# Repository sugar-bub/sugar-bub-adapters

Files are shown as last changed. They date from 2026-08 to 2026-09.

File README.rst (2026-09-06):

Sugar Bub Adapters
==================

.. contents::

Cartridge Hardware
------------------

Cartridge hardware is built around a 45-pin FPC cable. One end connects to a cartridge-type PCB:

* `Base Adapter`_
* `GG Adapter`_

The other end connects to a slot-type PCB:

* `RetroSix GameSlot`_
* `SMS Adapter`_
* `SG-1000 Adapter`_

.. _RetroSix GameSlot: https://retrosix.co.uk/Game-Gear-GameSlot-Kit-p515558760

Base Adapter
~~~~~~~~~~~~

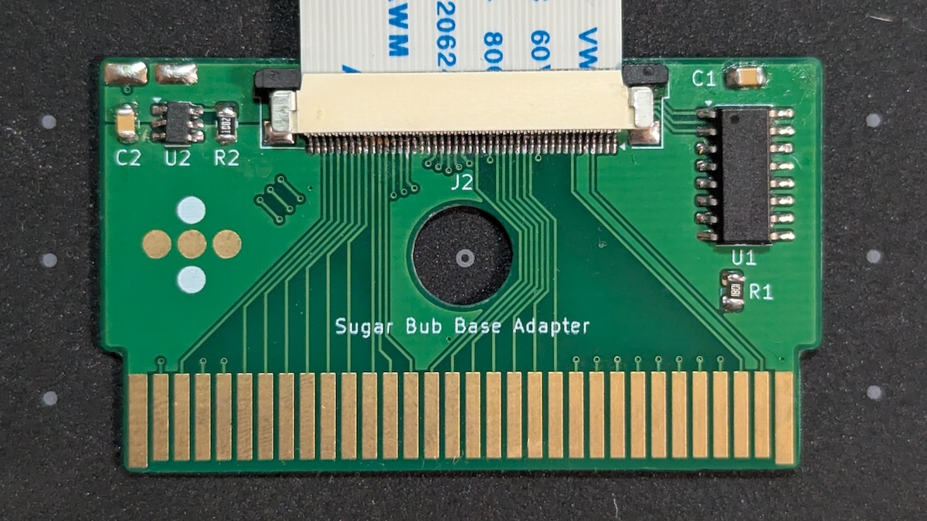
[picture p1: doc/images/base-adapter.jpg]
Base adapter with all components populated for Analogue Pocket compatibility.


The base adapter can be inserted into a Game Boy cartridge slot. It adapts the Game Boy cartridge interface to a FPC connector with the same pinout mapping as the `Analogue AP-A01`_ Sega Game Gear adapter. This FPC connector can be connected directly to a `RetroSix GameSlot`_ or the Sugar Bub `SMS Adapter`_.

By harvesting the MCU from an AP-A01, the adapter can be made compatible with the `Analogue Pocket`_. However, without harvesting the MCU_ or reverse-engineering its communication protocol, the Pocket will not recognize the adapter.

.. _Analogue AP-A01: https://github.com/sfiera/pocket-adapters/blob/main/gg.md
.. _Analogue Pocket: https://www.analogue.co/pocket
.. _MCU: https://github.com/sfiera/pocket-adapters/blob/main/mcu.md

PCB requirements:

* ENIG or hard gold finish (not HASL)
* 0.8mm thickness

Components:

* FPC cable (45p, 0.5mm pitch)
* J2: Amphenol F32Q-1A7H1-11045 FPC connector (45p, 0.5mm pitch)
* U1: SOIC-16 HC139 demux
* C1: 0.1uF 0805 SMD capacitor
* (optional) U2: MCU from Analogue AP-A01
* (optional) C2: 0.1uF 0805 SMD capacitor
* (optional) R1: 1.2k 0805 SMD resistor
* (optional) R2: 10k 0805 SMD resistor
* (optional) D1: 0402 IR LED

SMS Adapter
~~~~~~~~~~~

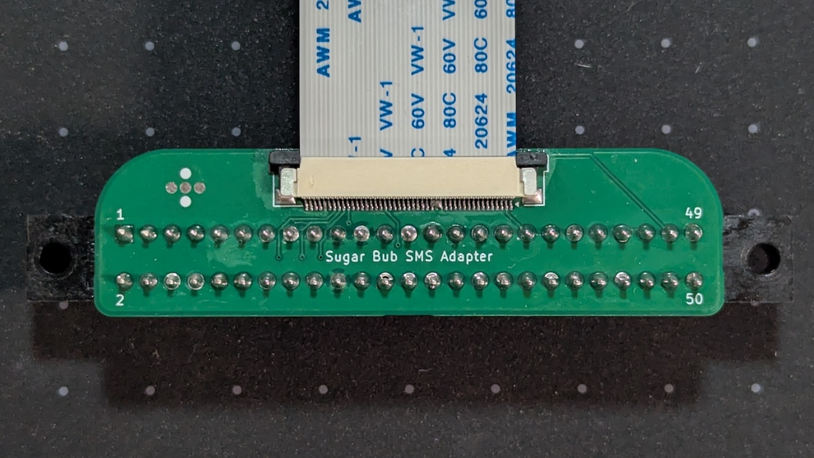
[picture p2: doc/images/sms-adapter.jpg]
SMS adapter with components soldered.


In combination with the `base adapter`_, the SMS adapter serves as a `Master Gear Converter`_ without the need of an intermediate Game Gear slot.

.. _Master Gear Converter: https://segaretro.org/Master_Gear_Converter

PCB requirements:

* Any finish
* Any thickness

Components:

* Amphenol F32Q-1A7H1-11045 FPC connector (45p, 0.5mm pitch)
* EDAC 395-050-521-802 edge connector (50-pin, 2.54 mm pitch)

SG-1000 Adapter
~~~~~~~~~~~~~~~

  **Warning**

  Still needs work. Through-hole diameter is too small.

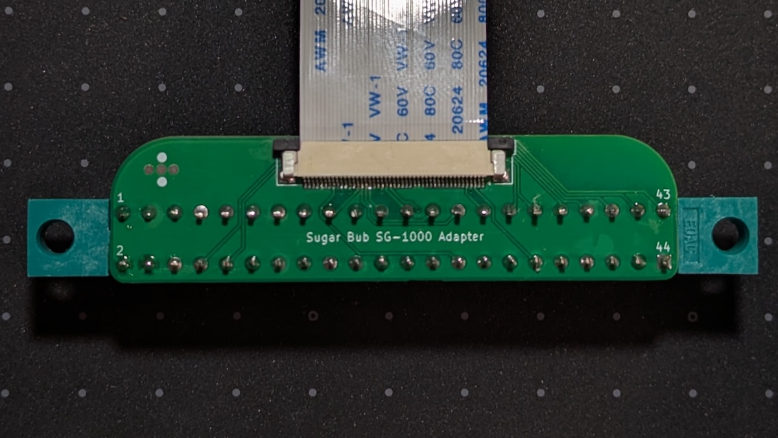
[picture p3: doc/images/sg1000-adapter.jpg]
SG-1000 adapter with components soldered.


In combination with the `base adapter`_, the SG-1000 adapter serves as a `Master Gear Converter`_ for Japanese cartridges without the need of an intermediate Game Gear slot or region converter.

PCB requirements:

* Any finish
* Any thickness

Components:

* Amphenol F32Q-1A7H1-11045 FPC connector (45p, 0.5mm pitch)
* EDAC 346-044-560-204 edge connector (44-pin, 3.175mm pitch)

GG Adapter
~~~~~~~~~~

The GG adapter can be inserted into a Game Gear cartridge slot. It adapts the Game Gear cartridge interface to a FPC connector with the same pinout. This FPC connector can be connected to the Sugar Bub `SMS Adapter`_ to serve as a `Master Gear Converter`_.

Note that the +34V pin is left unconnected. This pin is used only by the TV Tuner.

PCB requirements:

* ENIG or hard gold finish (not HASL)
* 1.0mm thickness

Components:

* FPC cable (45p, 0.5mm pitch)
* J2: Amphenol F32Q-1A7H1-11045 FPC connector (45p, 0.5mm pitch)

Link Hardware
-------------

Link hardware is built around a classic `Macintosh printer cable`_. Like the `Gear-to-Gear cable`_, this is an 8-core cable with 3 crossover pairs. Unlike the Gear-to-Gear cable, it uses a standard 8-pin Mini-DIN connector.

If purchasing a cable, you need one with the following wiring (`example cable`_):

* 1 → 2, 2 → 1
* 3 → 5, 4 → 4, 5 → 3
* 6 → 8, 7 → 7, 8 → 6

.. _Macintosh printer cable: https://whitefiles.org/tec/pgs/h10b.htm
.. _Gear-to-Gear cable: https://segaretro.org/Gear-to-Gear_Cable
.. _example cable: https://www.ebay.com/itm/371981646916

GG Link Adapter
~~~~~~~~~~~~~~~

  **Warning**

  Untested!

The GG link adapter plugs into a `Master Link Cable`_, which in turn plugs into a Game Gear’s EXT port in place of a Gear-to-Gear cable.

.. _Master Link Cable: https://segaretro.org/Master_Link_Cable

Pmod Link Adapter
~~~~~~~~~~~~~~~~~

  **Warning**

  Untested!

The Pmod link adapter plugs into the Pmod connector on top of a `Game Bub`_. It also requires connection to the link port by a Game Boy (not GBA) link cable.

.. _Game Bub: https://gamebub.net/

Q&A
---

Q: What hardware is compatible with the `Base Adapter`_?
  A: Compatible hardware currently includes:

  * `Analogue Pocket`_, which can play games if U2 is harvested from an `Analogue AP-A01`_
  * `GBxCart RW`_, which can use cartload_ to back up cartridges

  Support is planned for `Game Bub`_.

.. _GBxCart RW: https://www.gbxcart.com/
.. _cartload: https://cartload.org/

Q: What’s the use of supporting the Pocket if you need to cannibalize an existing adapter?
  A: Not much, truthfully. But there are a couple of minor reasons you might prefer it:

  * You can use same adapter on all systems, which is slightly more convenient.
  * You can access the `output of U2`_ from a solder pad, which simplifies reverse-engineering.
  * You can connect an `SMS Adapter`_ or `SG-1000 Adapter`_, which means fewer adapters to play SMS/SG-1000.
  * You can customize the adapter shell, which lets the Game Gear (or other) cartridge sit lower.

.. _output of U2: https://github.com/sfiera/pocket-adapters/blob/main/mcu.md

Q: Will there be a link adapter for the Pocket?
  A: No, Gear-to-Gear cables have 7 data pins, and there’s no good way to get more than 4 out of the Pocket.

Q: Is there any further documentation of the Analogue Pocket adapters?
  A: Yes, see `sfiera/pocket-adapters`_.

.. _sfiera/pocket-adapters: https://github.com/sfiera/pocket-adapters

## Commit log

2026-02-19 Widen via holes
    [base.kicad_pcb, sms.kicad_pcb]
2026-02-19 Fix SMS pin ordering
    [sms.kicad_pcb, sms.kicad_sch]
2026-03-02 Straighten one +5V trace
    [base.kicad_pcb]
2026-03-02 Flip HC139 text to match chip orientation
    [base.kicad_pcb]
2026-04-10 Narrow fingers and move D1 to right side
    [base.kicad_pcb, base.kicad_sch]
2026-04-10 Adjust adapter PCB dimensions
    [base.kicad_pcb]
2026-04-10 Make cap and resistors 0805 for easier soldering
    [base.kicad_pcb, base.kicad_sch]
2026-04-10 Narrow programming fingers to 1mm too
    [base.kicad_pcb]
2026-04-10 Widen adapter board to 52.4mm
    [base.kicad_pcb]
2026-04-13 Redo SMS adapter
    [sms.kicad_pcb, sms.kicad_sch]
2026-04-13 Add additional decoupling cap to base adapter
    [base.kicad_pcb, base.kicad_sch]
2026-04-13 Add /Refresh to SMS and shrink logo
    [base.kicad_pcb, base.kicad_sch, sms.kicad_pcb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]
2026-04-14 Mark Analogue Pocket components as DNP
    [base.kicad_pcb, base.kicad_sch]
2026-04-14 Add SG-1000 adapter
    [sg1000.kicad_pcb, sg1000.kicad_sch]
2026-04-14 Move SMS adapter text to center
    [sms.kicad_pcb]
2026-04-17 Add Game Gear base adapter
    [gg.kicad_pcb, gg.kicad_sch]
2026-04-19 Add link adapters
    [link-gg.kicad_pcb, link-gg.kicad_sch, link-pmod.kicad_pcb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]
2026-04-25 Use M3 mounting screw footprint
    [link-gg.kicad_pcb, link-pmod.kicad_pcb]
2026-04-25 Update output directories
    [gg.kicad_pcb, link-gg.kicad_pcb, link-pmod.kicad_pcb]
2026-05-13 Fix orientation of link-pmod GB link port
    [link-pmod.kicad_pcb]
2026-05-14 Widen GG cart edge footprint and add holes
    [gg.kicad_pcb]
2026-08-23 Correct edge connector information
2026-08-23 Upgrade KiCad
    [base.kicad_pcb, base.kicad_sch, gg.kicad_sch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]
2026-08-23 Fix SG-1000 adapter slot pitch
    [sg1000.kicad_pcb, sg1000.kicad_sch]
2026-08-25 Document serial cable wiring
2026-08-27 Expand printer cable wiring for clarity
